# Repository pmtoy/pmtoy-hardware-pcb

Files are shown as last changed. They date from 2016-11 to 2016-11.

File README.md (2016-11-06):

# pmtoy-hardware-pcb
空气质量检测模块，主控 STM32F070F6 ，主传感器采用攀藤科技 PMS7003 ，带有 1.4寸 TFT显示 和 USB传输

## 硬件部分

+ 主控 STM32F070F6
+ UART, PMS7003 传感器
+ SPI, 1.4寸 TFT 显示
+ 开关，3.3V 电源转换
+ 按钮，芯片RESET 
+ 按钮，编程
+ LED， 编程
+ USB， 供电 + 通讯
+ SWD 接口

## 已知问题

+ 传感器模块接口插孔太小，导致接口无法完整插入，焊锡连接的情况下，不影响使用。
+ 接上传感器模块后，3.3V 供电无法开关切换，原因: 传感模块 5V 电源没有考虑开关
+ USB DP 1.5k 上拉电阻没有必要，芯片内部已经实现了，故独立使用LED功能.

## 原理图

[PDF Version](Output/PMToy.pdf)

## 实物照片

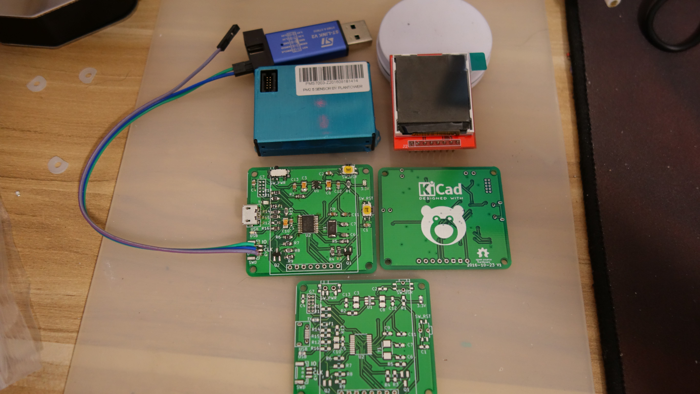
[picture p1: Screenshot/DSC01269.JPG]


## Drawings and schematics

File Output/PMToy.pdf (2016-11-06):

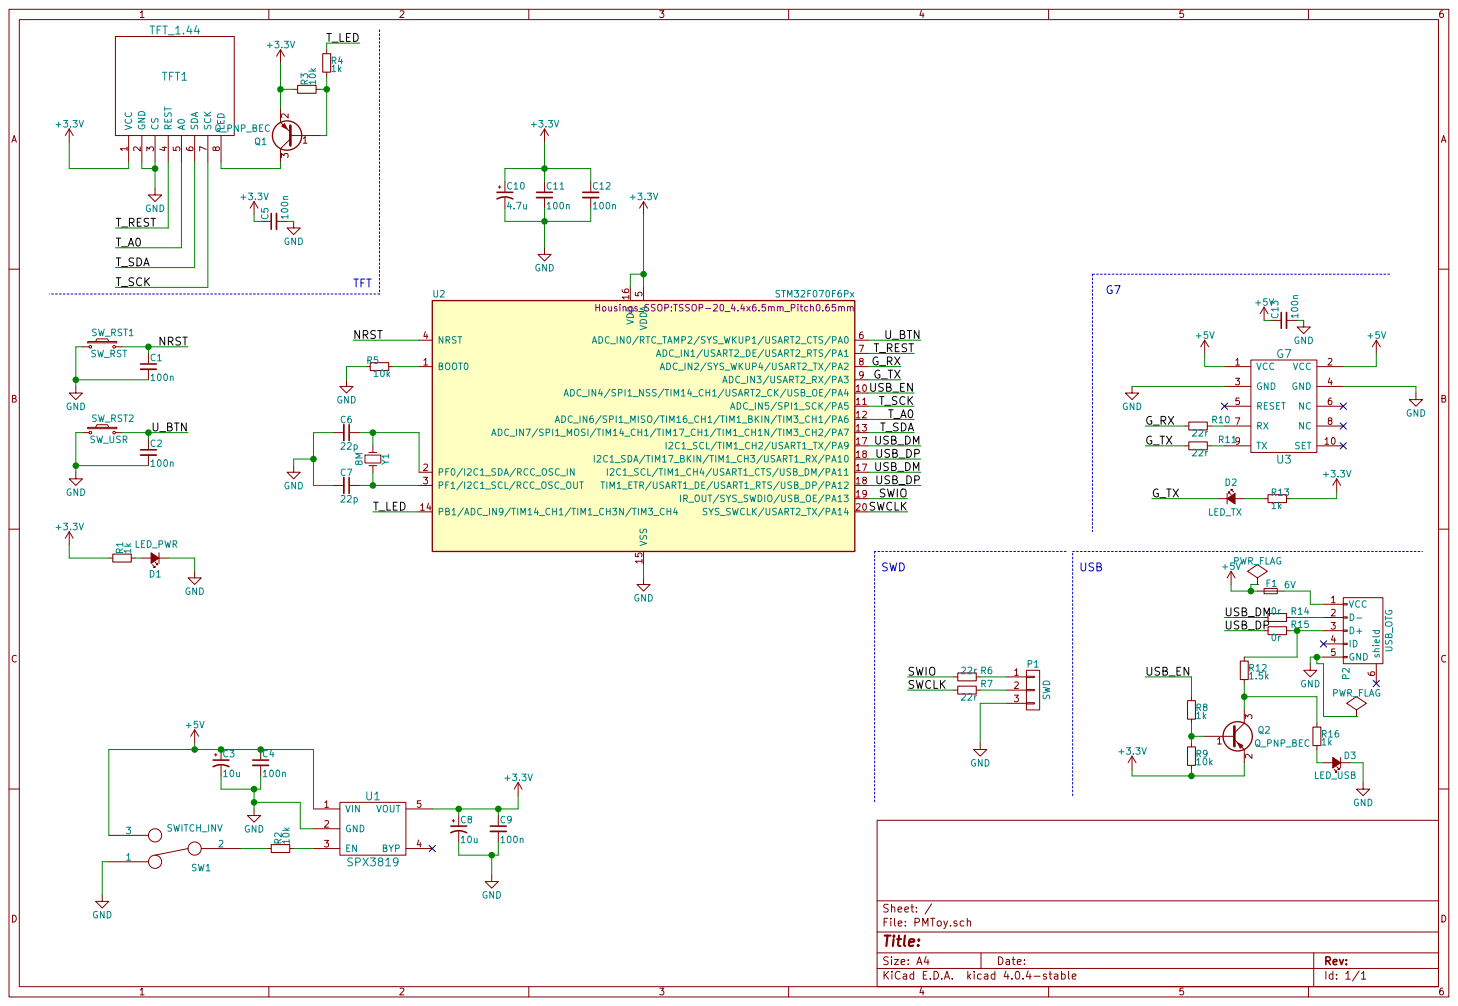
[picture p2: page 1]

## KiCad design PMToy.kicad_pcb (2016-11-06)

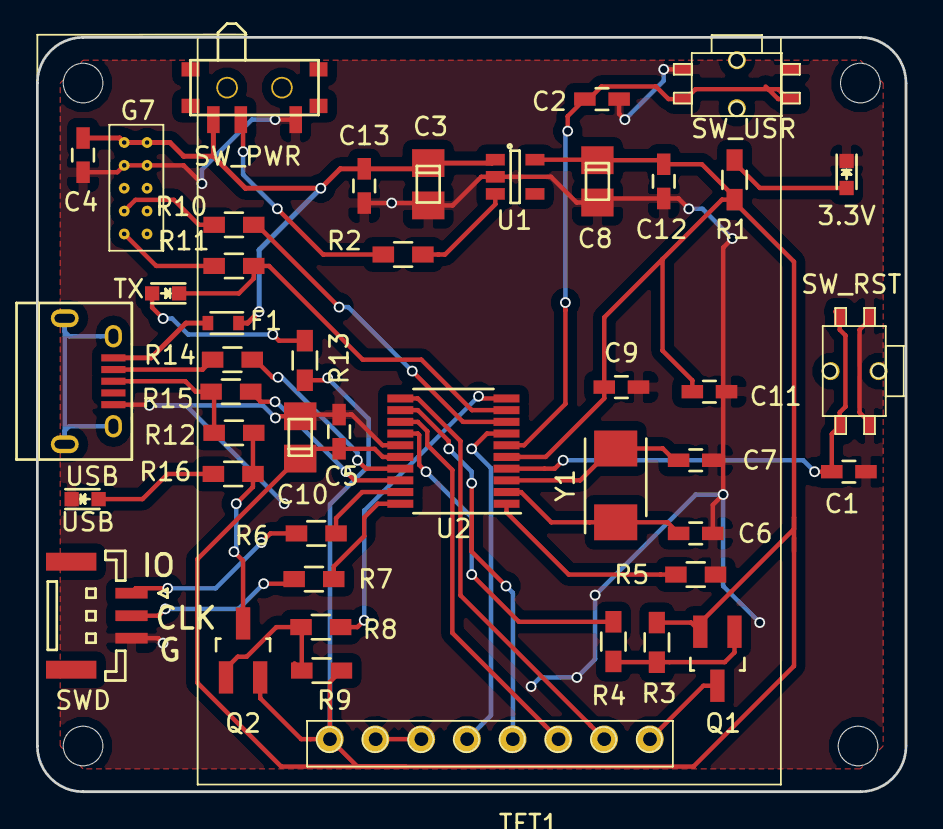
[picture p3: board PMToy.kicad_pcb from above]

Board: 2 copper layers, 48.3 x 41.9 mm, 45 parts (0 on the bottom side), 36 nets.

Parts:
3.3V: LED_PWR; LED_0603
C1, C2, C4, C5, C9, C11, C12, C13: 100n; C_0603_HandSoldering
C3, C8: 10u; TantalC_SizeR_EIA-2012
C6, C7: 22p; C_0603_HandSoldering
C10: 4.7u; TantalC_SizeR_EIA-2012
F1: 6V; D_0603
G7: G7; PMS7003_2
Q1, Q2: Q_PNP_BEC; SOT-23_Handsoldering
R1, R4, R8, R13, R16: 1k; R_0603_HandSoldering
R2, R3, R5, R9: 10k; R_0603_HandSoldering
R6, R7, R10, R11: 22r; R_0603_HandSoldering
R12: 1.5k; R_0603_HandSoldering
R14, R15: 0r; R_0603_HandSoldering
SWD: CONN_01X03; JST_GH_BM03B-GHS-TBT_03x1.25mm_Straight
SW_PWR: SWITCH_INV; SSSS811101
SW_RST1: SW_RST; MBTN1
SW_RST2: SW_USR; MBTN1
TFT1: TFT_1.44; TFT1.44
TX: LED_TX; LED_0603
U1: SPX3819; SOT-23-5
U2: STM32F070F6Px; TSSOP-20_4.4x6.5mm_Pitch0.65mm
USB: LED_USB; LED_0603
USB#2: USB_OTG; USB_Micro-B
Y1: 8M; Crystal_SMD_5032_2Pads

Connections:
+3V3: C5.1, C8.1, C9.1, C10.1, C11.1, C12.1, Q1.2, Q2.2, R1.1, R3.1, R9.2, R13.1, TFT1.1, U1.5, U2.5, U2.16
+5V: C3.1, C4.1, C13.1, F1.1, G7.1, G7.2, SW_PWR.3, U1.1
/G_RX: R10.2, U2.8
/G_TX: R11.2, TX.1, U2.9
/NRST: C1.1, SW_RST1.2, U2.4
/SWCLK: R7.2, U2.20
/SWIO: R6.2, U2.19
/T_A0: TFT1.5, U2.12
/T_LED: R4.1, U2.14
/T_REST: TFT1.4, U2.7
/T_SCK: TFT1.7, U2.11
/T_SDA: TFT1.6, U2.13
/USB_DM: R14.2, U2.17
/USB_DP: R15.2, U2.18
/USB_EN: R8.1, U2.10
/U_BTN: C2.1, SW_RST2.2, U2.6
GND: 3.3V.1, C1.2, C2.2, C3.2, C4.2, C5.2, C6.2, C7.2, C8.2, C9.2, C10.2, C11.2, C12.2, C13.2, G7.3, G7.4, R5.2, SWD.3, SW_PWR.1, SW_RST1.1, SW_RST2.1, TFT1.2, TFT1.3, U1.2, U2.15, USB.1, USB#2.5
unnamed: C6.1, U2.2, Y1.1
unnamed: C7.1, U2.3, Y1.2
unnamed: 3.3V.2, R1.2
unnamed: R13.2, TX.2
unnamed: R16.2, USB.2
unnamed: F1.2, USB#2.1
unnamed: R6.1, SWD.1
unnamed: R7.1, SWD.2
unnamed: R14.1, USB#2.2
unnamed: R12.1, R15.1, USB#2.3
unnamed: Q1.1, R3.2, R4.2
unnamed: Q1.3, TFT1.8
unnamed: Q2.1, R8.2, R9.1
unnamed: Q2.3, R12.2, R16.1
unnamed: R2.1, SW_PWR.2
unnamed: R2.2, U1.3
unnamed: R5.1, U2.1
unnamed: G7.7, R10.1
unnamed: G7.9, R11.1

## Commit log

2016-11-06 first version pcb.
    [PMToy-B.Adhes.gbr, PMToy-B.Cu.gbr, PMToy-B.Mask.gbr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]
2016-11-06 PCB Image
